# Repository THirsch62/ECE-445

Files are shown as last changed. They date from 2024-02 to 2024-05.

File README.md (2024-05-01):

# Senior Design Spring 2024 Lab Notebook
Group: Tyler Hirsch, Bryson Maedge, Nolan Opalski  
NetId: &nbsp;thirsch3, &nbsp;&nbsp;&nbsp;&nbsp;&nbsp;&nbsp;bmaedge2, &nbsp;&nbsp;&nbsp;&nbsp;&nbsp;&nbsp;&nbsp;&nbsp;nolanfo2   
TA: &nbsp;&nbsp;&nbsp;&nbsp;&nbsp;&nbsp;Angquan Yu

## May 1st, 2024
Finished our final paper today and am adding the last update to the notebook. Has been a very informative class and we all learned a lot. Thank you!

## April 30th, 2024
We each individually worked on the final paper throughout the day. Made some really solid progress only need to do the R&V Portion of the paper now.

## April 29th, 2024 (Presentation)
Today we had our presentation. We believe it went really well. It was at 8am which was a little bit of an early wakeup for us but our minds were sharp. 

## April 28th, 2024
We took the feedback from our mock presentation and edited our slides. We also ran through the presentation once and got fluid with our speaking. We are ready for this.

## April 26th, 2024 (Mock Presentation)
We met at 10AM to perform our mock presentation. We got a lot of valuable feedback that we are going to apply to our slides. Presentation went far better than the demo.

## April 25th, 2024
We met at 12:30 to review everything we compiled for our presentation. We also put together our team contract fulfillment.

## April 24th, 2024
We met briefly on discord to go over rough layout of our presentation.

## April 23rd, 2024 (Final Demo)
We demoed our project to Professor Gruev and 2 TAs. They were rather unimpressed to say the least. We didn't read the PCB requirements, so we didn't put a microcontroller on the board, so we lost points for that. We tried to explain what happened with our Raspberry Pi and the image recognition but it didn't look like they were buying it. To be fair, it does sound far-fetched. We were basically told that this stuff happens all the time and that we need to try harder.

## April 22nd, 2024
Our Raspberry Pi came in. We retested the control of all the servos to make sure that functionality worked. We started getting a lot of errors surrounding keras and tensorflow. We spent about 4 hours trying different methods to install keras and tensorflow and it wouldn't load on this Raspberry Pi.

## April 20th, 2024
At some point during the past night, 2 panels came off our project and the power port for our Raspberry Pi came off. We cut new panels and reglued them. We also ordered a new Raspberry Pi.

## April 18th, 2024 (Mock Demo)
We demoed our project to Angquan. He was very impressed with our project and to see that it was working.

## April 17th, 2024
We met at noon today to test everything folding. The board was able to fold as expected. Our image recognition was not accurate, so we painted the board black to try to achieve better results if we increased our contrast. After painting our system was correctly able to distinguish between pants and shirts.

## April 16th, 2024
Nolan glued the servos to the board at noon so they would be dry and ready for testing by tomorrow. Tyler tested all the ports on the Raspbery Pi and the PCB and made sure they were able to interact with the button, LEDs and servos.

## April 15th, 2024
Tyler and Nolan met around 3:30 to solder everything to the PCB.

## April 11th, 2024
We met at noon today. We almost finished rebuilding the project with 6 servos for control instead of 12. We also finished designing our PCB and submitted an order through JLCPCB to get our PCB in sooner.

## April 10th, 2024
We met at 2pm today. We started rebuilding our project. We had to recut panels that were suited for 1 servo.

## April 9th, 2024
We met at 2pm today. Last time we met, we were not able to emit enough voltage to power the servos. We were limited by the voltage supplied by the IC chip. After meeting today, we were still unable to resolve this issue and decided it would be easiest to switch our design to only utilize one servo.

## April 3rd, 2024
We met at 1pm today. The goal was to finalize how we could utilize transistors to control power to our servos.

## April 2nd, 2024 (Fourth Round PCB Way Deadline at 4:45pm)
We met today and finished our PCB design. We sent it over to our TA for audit and it failed. We are going to send our own order in tomorrow morning. Here is a picture of our design.

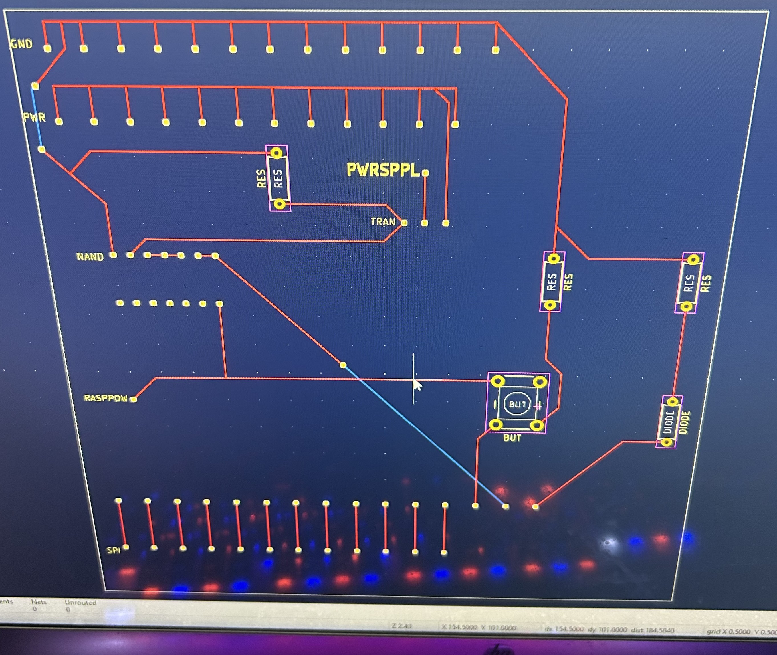
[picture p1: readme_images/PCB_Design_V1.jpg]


## April 1st, 2024
We met today at 2pm to finish glueing everything. We finished:
* Glueing servo arms to panels
* Glueing servos to risers
* Glueing camera arm mount to board
* Glueing Rasperry Pi riser to board  

Before we could attach the servos to the panels, we had to set the servos on the left of the panel to an initial position of 0 degrees, and the serovs on the right of the panel to an initial position of 180 degrees. This is because they will be turning in opposite directions. So, in the "fold-up" position, the left servo will be rotated to a 120 degree angle and the right servo will be rotated to a 60 degree angle. We ran into a problem with our Raspbeery Pi today. It kept booting on and off for about 2 hours before it stabilized. We were never able to identify the cause of the problem, but we hope it does not continue and we are forced to spend another $60 on a Raspberry Pi.

We started testing once the glue finished curing. We started by rotating the servos 18 degrees and back to the starting position and it worked great. We then tried testing it by rotating the servos 90 degrees and then back. There was a loud cracking noise and we realized we overtorqued one of the servos and it was not out of commission. One of our risers is also broken, but that's an easier fix. Now, we need to order more servos before we can continue working.

We identified the problem as the PWM signal. When our code is not running and everything is connected to power, the servos are reading a PWM duty cycle of 0%, therefore they both try to rotate to their starting position. This will cause them to break, as happened during our initial test. We decided that we could fix this problem by using a PNP transistor. If the servos have no power to them, they cannot rotate, no matter what the PWM duty cycle is. Our idea is, we will set the PWM duty cycles of all the servos and then use logic to allow power to pass through to servos. Then whenever we need to stop the program or anything, we just cut power to our servos, so they don't try to rotate to a wrong position.

The Raspberry Pi's GPIO ports has a low signal of ~1.2V and a high signal of ~4.9V. This will not work as a transistor will generally start allowing passthrough voltage at anything over ~0.7V. Therefore we will need to add an IC chip, to help control this output. The IC chip will be a NAND gate as that is the easiest to convert to an AND gate and none of the 3 of us have any AND chips. (Here is a <a href="https://www.ti.com/lit/ds/symlink/sn74ac00.pdf?ts=1711955865754&ref_url=https%253A%252F%252Feu.mouser.com%252F">link</a> to the NAND gate's data sheet) The NAND gate's output will have a high signal of ~2.1V and a low signal of ~0.1V. This will allow us to properly control a transistor. We will connect our power supply's Vin to the collector pin of the transistor and connect our servos to the emitter pin of the transistor. This will allow us to control a higher voltage circuit with a lower voltage Raspberry Pi.

We tested this today with a transistor from a previous ECE class lab kit, but the maximum throughput was 3.3V. We need 5V minimum to power our servos, so we will need to order others. We also have a fleshed out version of our PCB, but are waiting on last minute parts to test on a breadboard before we submit a PCB order.

We stopped working around 8:30PM.

We are waiting on the following parts to come in:
* Spool of 22 AWG wire
* Wire stripper
* Female to male wires
* Raspberry Pi Camera cable extension
* Replacement servos (they come in packs of 4)
* Transistors

## March 27th, 2024
We met today to get some more physical aspects of the project done. Here's what we finished today:
* Glueing dowels to panels for structural support
* Built and glued 12 risers for all servos
* Built riser for Raspberry Pi
* Built camera arm
* Built mount for camera arm

## March 25th, 2024
We met again today to start building our project. We cut out the first panels and realized we couldn't cut our dowel rods with a box cutter, so we ran back to Home Depot. We bought:
* Pruners (easy way to cut dowels)
* Another dowel (Mount camera)

On the way back, we stopped at Goodwill and bought infant clothes to demo. We finished cutting all of the dowels and started cutting the risers as well.

## March 21st, 2024
We met at noon today to revise project plans and get supplies. We decided that we would use cardboard for panels and for a base because it would be light and within our budget. We would reinforce the cardboard with dowel rods and use superglue/gorilla glue to hold everything together.

We did a Home Depot run. We bought:
* 2 Heavy duty cardboard boxes. 
    * 1 will be used as a baseplate for the entire project
    * The other will be cut up and used as panels for folding clothes and as risers for the servos
* Box cutter
    * Cut cardboard
* Dowel rod
    * Cut into pieces and used to mount servos to panels
* Gorilla glue
    * Mount risers to baseplate and servos to risers
    * Mount dowel rod to servo

## March 19th, 2024
After a series of emails were sent around, we were able to locate the rest of our Amazon order. We had a team meeting at 3pm to discuss project details and to pick up the rest of our order.<br><br>
We met with Angquan for our weekly check-in at 4pm.<br><br>
After the meeting we experimented with our Servos to make sure we could control 2 of them simultaneously.

## March 6th, 2024
We went to the ECEB to pick up our amazon order that we placed through ECE Illinois. Part of our order was missing. Started emailing around to find where the rest of the order could be.

## February 27th, 2024 (Design Review Date)
We presented our Design Document to 3 TAs and Professor Viktor Gruev. Some feedback that was provided:
* Find other voltage regulator. Linear one we are currently using allows more power dissipation.
* Use children's clothes. Will scale size of model down and can save on materials.
* Include more data about architecture and design of Image Recognition subsystem. Such as how many layers, what features we use to classify, etc., and why we chose all those.
* Add what data is being transferred in the block diagram
* Add temperature to Tolerance Analysis

## February 26th, 2024
We determined who was going to present each part of the design document tomorrow and had a few practice presentations.<br>

We found out that 3-D printing everything would be very expensive. So we decided that we'll use 2x2's or something of the like from Home Depot for the frame. A veneer or polyester sheet for the panels. And then we would 3-D print the mounting mechanisms so that we ensure a proper fit for the servos.

## Februrary 22nd, 2024 (Design Document Due Date)
We finalized our <a href="https://github.com/THirsch62/ECE-445/blob/main/Design%20Document.pdf">Design Document</a>, referencing the <a href="https://courses.engr.illinois.edu/ece445/documents/grading_rubrics/DD_evalsheet.pdf">evaluation sheet</a> to make sure that we met all the requirements.

## Februrary 21st, 2024
We met today to revise our Design Document and started CAD modeling. We determined how much 3D printing would cost us and also placed an Amazon order through ECE Illinois for all parts we need to start our initial testing.
<br><br>
Here is the start of what our panels will look like:
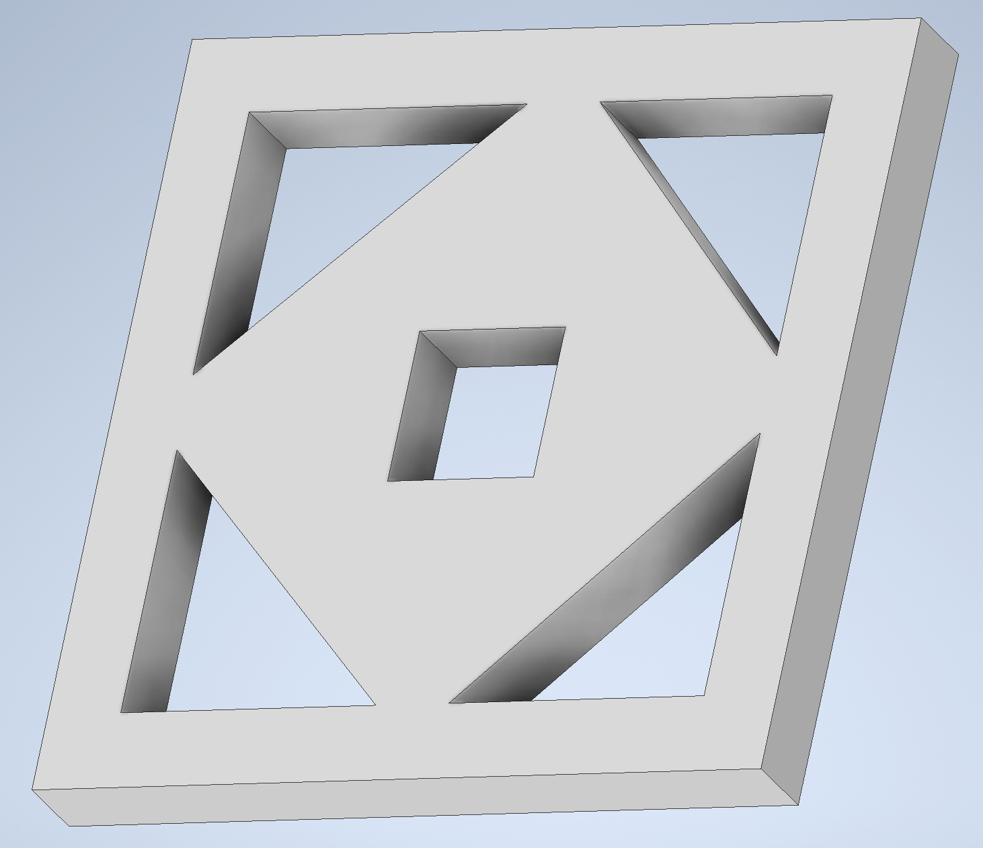
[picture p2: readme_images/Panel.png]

The dimensions are 10"x10"x1".
<br><br>
Here is our purchase order:
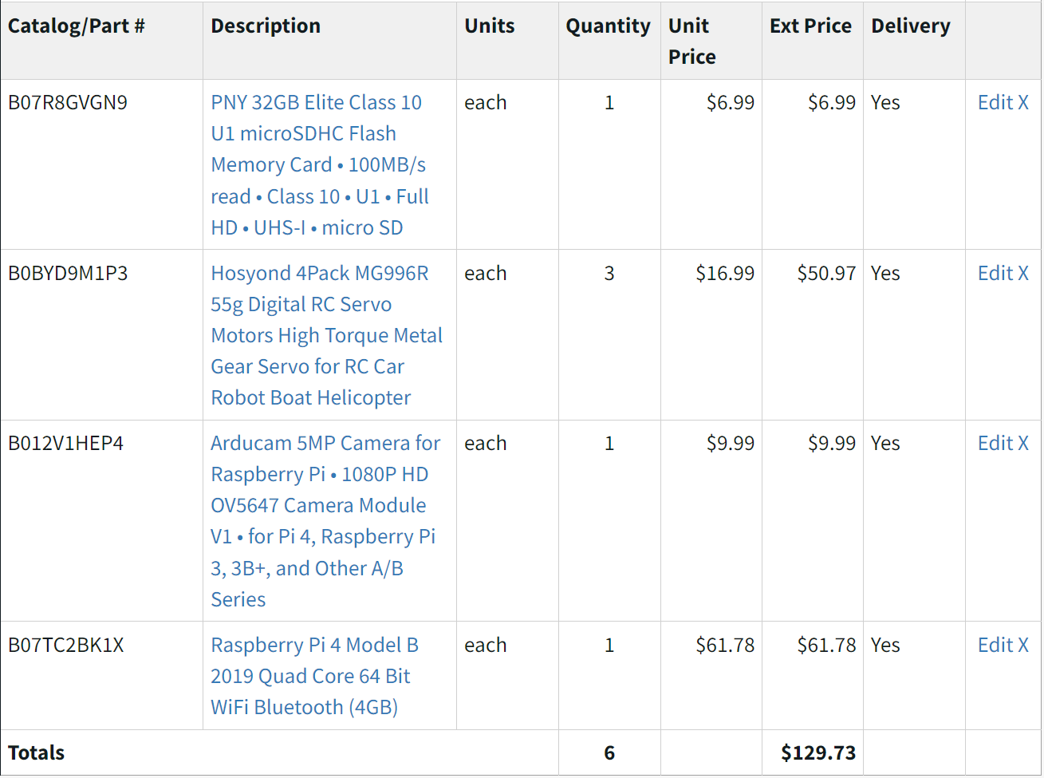
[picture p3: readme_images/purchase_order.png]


## February 20th, 2024
We finished a rough draft of our Design Document and reviewed it with our TA. We determined that our graphics should be more detailed and our verification steps should be more objective.

## February 19th 2024
We started a rough draft of our Design Document. We plan to work on it tonight and tomorrow. This way, we'll have a good outline before meeting with our TA so we can get any help if needed.

## February 18th 2024
Sent emails asking for discounts/sponsored free parts to:
- DFRobots (Servos)
- RaspberryPi (RaspberryPi4 and camera module)
- Siebel Center for Design (3-D printing)

## February 12th 2024
We discussed parts required for initial testing:
* Servos
* RaspberryPi 4
* Camera
* Frame to mount servos to
* Panel to attach to servos and test folding mechanism

We put together a shopping list with amazon links to stuff we need to purchase for testing so we can discuss purchasing procedure with our TA tomorrow. We also need to discuss the procedure for getting CAD models 3-D printed as our frame and panels will most likely be 3-D printed.

## February 9th 2024 (Team Contract Due Date)
We discussed guidelines, goals and expectations today. Following that discussion, we put together our <a href="https://github.com/THirsch62/ECE-445/blob/main/ECE445_Team_48_Contract.pdf">Team Contract</a> and submitted on Canvas.

## February 8th 2024 (Project Proposal Due Date)
We collaborated over discord to make revisions in accordance to feedback provided by our Ta.  
<a href="https://github.com/THirsch62/ECE-445/blob/main/Project%20Proposal.pdf">Project Proposal</a> was submitted by Nolan on Canvas.
<br><br>
Started <a href="https://github.com/THirsch62/ECE-445/tree/main/python_code">python code</a> for image recognition:
* Import dataset from MNIST
* Isolate and extract part of data we need (training images and labels for: tshirts, pullovers, trousers)
* Train CNN on extracted data (model predicts with 97.7% accuracy on test dataset)
* Save trained model to sdcard
* Load trained model into memory
* Function to accept image and output predicted classification

Miscellaneous code:
* Created general layout for future functions
* TODO: Function to normalize image from camera. Will consist of cropping image to just clothing item and resizing image to 28x28 pixels
* TODO: Set up basic servo control function. Input parameter will be int corresponding to panel to fold. Function will execute folding for that panel
* TODO: Figure out folding pattern/series of ints to pass to servo control function. Need 3 foloding patterns for all clothing types

## February 7th 2024 (First TA meeting)
We met with our TA (Angquan Yu) at 4pm. Recieved feedback on current status of our project Proposal.  
Feedback summary:  
* Needs to be more detailed
* Clarified that PCB will be part of servo subsystem in our physical system  

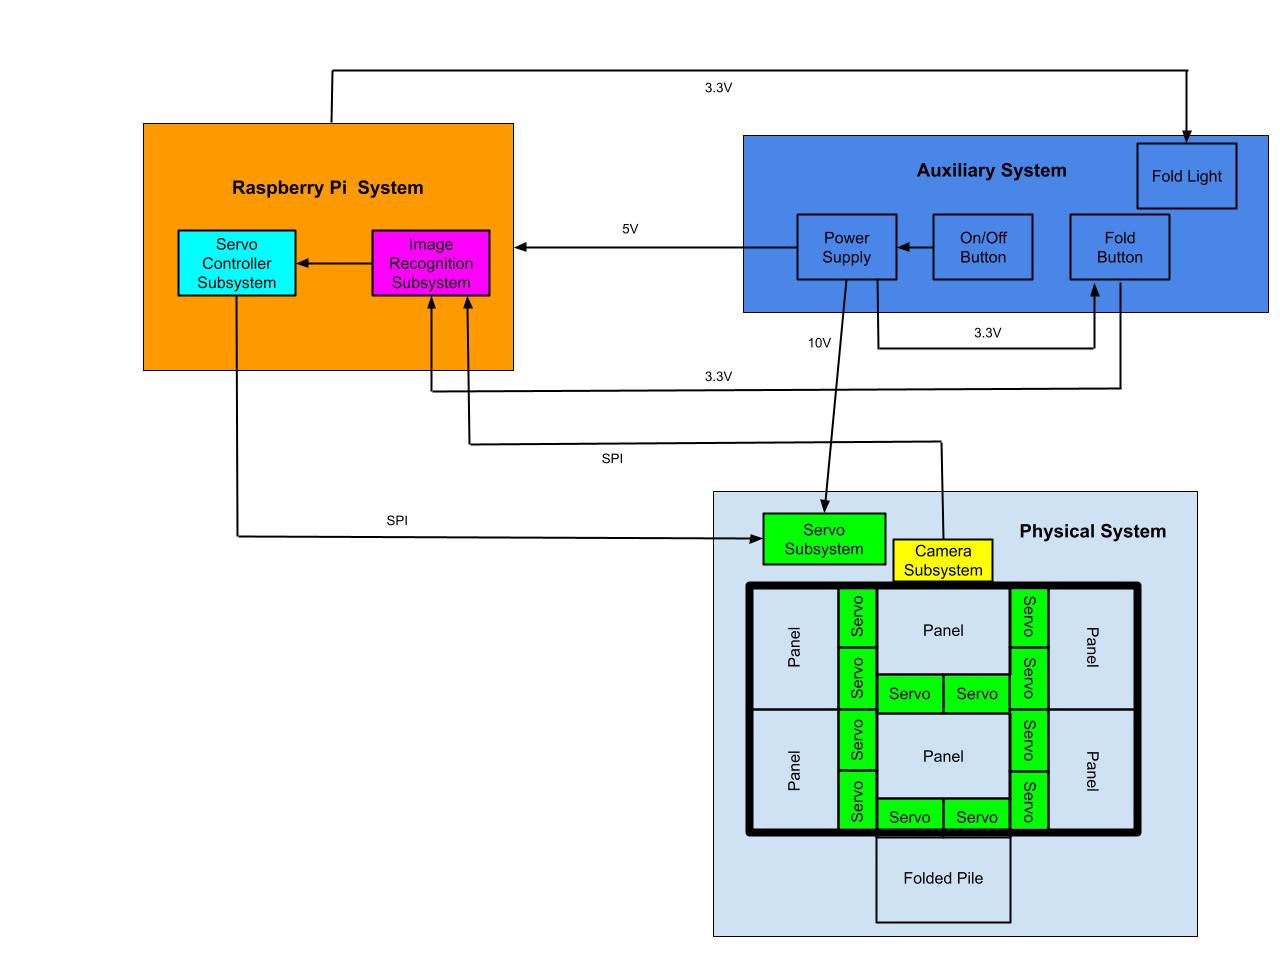
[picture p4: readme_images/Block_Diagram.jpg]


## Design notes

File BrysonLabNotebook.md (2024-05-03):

# Senior Design Spring 2024 Lab Notebook Bryson
Group: Tyler Hirsch, Bryson Maedge, Nolan Opalski  
NetId: &nbsp;thirsch3, &nbsp;&nbsp;&nbsp;&nbsp;&nbsp;&nbsp;bmaedge2, &nbsp;&nbsp;&nbsp;&nbsp;&nbsp;&nbsp;&nbsp;&nbsp;nolanfo2   
TA: &nbsp;&nbsp;&nbsp;&nbsp;&nbsp;&nbsp;Angquan Yu

## May 2nd, 2024
Added some personal thoughts to each entry of the lab notebook to make it pertain more specifically to me. Had a lot of the same information as this project was truly collaborative. Each time we met we usually met as a group and worked on it. Also turned in lab materials on time.

## May 1st, 2024
Finished our final paper today and am adding the last update to the notebook. Has been a very informative class and we all learned a lot. Thank you!

## April 30th, 2024
We each individually worked on the final paper throughout the day. Made some really solid progress only need to do the R&V Portion of the paper now. Feels very high quality. Need to add some details throughout.

## April 29th, 2024 (Presentation)
Today we had our presentation. We believe it went really well. It was at 8am which was a little bit of an early wakeup for us but our minds were sharp. I believe the professor enjoyed it and liked how we took his feedback and advocated for ourself.

## April 28th, 2024
We took the feedback from our mock presentation and edited our slides. We also ran through the presentation once and got fluid with our speaking. We are ready for this. Feeling wayyyy better than I did for the demo. 

## April 26th, 2024 (Mock Presentation)
We met at 10AM to perform our mock presentation. We got a lot of valuable feedback that we are going to apply to our slides. Presentation went far better than the demo. The communication related TA helped a lot with our actual presentation skills and the course TA helped us refine some technical displays of our project. Feeling confident going into the presentation.

## April 25th, 2024
We met at 12:30 to review everything we compiled for our presentation. We also put together our team contract fulfillment.

## April 24th, 2024
We met briefly on discord to go over rough layout of our presentation. Worked on some seperation of parts and who is going to say what. We are all good presenters so I am not worried,

## April 23rd, 2024 (Final Demo)
We demoed our project to Professor Gruev and 2 TAs. They were rather unimpressed to say the least. We didn't read the PCB requirements, so we didn't put a microcontroller on the board, so we lost points for that. We tried to explain what happened with our Raspberry Pi and the image recognition but it didn't look like they were buying it. To be fair, it does sound far-fetched. We were basically told that this stuff happens all the time and that we need to try harder. We got some really good feedback that I am glad to have heard. In the future, when I encounter problems I am going to make sure to better advocate what we did to solve them. I am kind of upset at how little we tried to explain our solution attempts because it would have made a much bigger difference. But now it is presentation time.

## April 22nd, 2024
Our Raspberry Pi came in. We retested the control of all the servos to make sure that functionality worked. We started getting a lot of errors surrounding keras and tensorflow. We spent about 4 hours trying different methods to install keras and tensorflow and it wouldn't load on this Raspberry Pi. I dont fully understand the problem since Tyler is the code wiz but things are starting to look bleak. Our image recognition just took a major step back and now it is time to demo.

## April 20th, 2024
2 panels fell off the project I noticed as I walked downstairs. We had to reglue them and do other little maintenance things like replace a servo that was not angling correctly. All went without a hitch.

## April 18th, 2024 (Mock Demo)
Tyler and Nolan demoed the project to Angquan. I was still studying for test but it worked. Was concerned about the paint, but our wires seem fine.

## April 17th, 2024
We met at noon today to test everything folding. The board was able to fold as expected. Our image recognition was not accurate, so me and Nolan painted the board black to try to achieve better results if we increased our contrast. After painting our system was correctly able to distinguish between pants and shirts. The paint hopefully did not get in any of the wiring which is a concern. We protected our servos so we will test once it dries.

## April 15-16th, 2024
Nolan and tyler did some soldering and some glueing. I had a test that I was studying for so was unable to be there.

## April 11th, 2024
We met at noon today. We almost finished rebuilding the project with 6 servos for control instead of 12. We then designed our PCB with me editing some footprints to fit our datasheet specific designs. We are going to submit an order on our own and fast track it so that we have time to mess around with it.

## April 10th, 2024
We met at 2pm today. We started rebuilding our project. I recut each panel and new risers for the servos in the morning. This allowed us to start working and thinking of new solutions right away.

## April 9th, 2024
We met at 2pm today. Last time we met, we were not able to emit enough voltage to power the servos. We were limited by the voltage supplied by the IC chip. After meeting today, we were still unable to resolve this issue and decided it would be easiest to switch our design to only utilize one servo.

## April 3rd, 2024
We met at 1pm today. The goal was to finalize how we could utilize transistors to control power to our servos. Nothing worked we need to rethink.

## April 2nd, 2024 (Fourth Round PCB Way Deadline at 4:45pm)
We met today and finished our PCB design. We sent it over to our TA for audit and it failed. We are going to send our own order in tomorrow morning. Here is a picture of our design. I am going to use my Kicad experience to make new PCB design hopefully we only need to order once.



## April 1st, 2024
We met today at 2pm to finish glueing everything. We finished:
* Glueing servo arms to panels
* Glueing servos to risers
* Glueing camera arm mount to board
* Glueing Rasperry Pi riser to board  

Before we could attach the servos to the panels, we had to set the servos on the left of the panel to an initial position of 0 degrees, and the serovs on the right of the panel to an initial position of 180 degrees. This is because they will be turning in opposite directions. So, in the "fold-up" position, the left servo will be rotated to a 120 degree angle and the right servo will be rotated to a 60 degree angle. We ran into a problem with our Raspbeery Pi today. It kept booting on and off for about 2 hours before it stabilized. We were never able to identify the cause of the problem, but we hope it does not continue and we are forced to spend another $60 on a Raspberry Pi.

We started testing once the glue finished curing. We started by rotating the servos 18 degrees and back to the starting position and it worked great. We then tried testing it by rotating the servos 90 degrees and then back. There was a loud cracking noise and we realized we overtorqued one of the servos and it was not out of commission. One of our risers is also broken, but that's an easier fix. Now, we need to order more servos before we can continue working.

We identified the problem as the PWM signal. When our code is not running and everything is connected to power, the servos are reading a PWM duty cycle of 0%, therefore they both try to rotate to their starting position. This will cause them to break, as happened during our initial test. We decided that we could fix this problem by using a PNP transistor. If the servos have no power to them, they cannot rotate, no matter what the PWM duty cycle is. Our idea is, we will set the PWM duty cycles of all the servos and then use logic to allow power to pass through to servos. Then whenever we need to stop the program or anything, we just cut power to our servos, so they don't try to rotate to a wrong position.

The Raspberry Pi's GPIO ports has a low signal of ~1.2V and a high signal of ~4.9V. This will not work as a transistor will generally start allowing passthrough voltage at anything over ~0.7V. Therefore we will need to add an IC chip, to help control this output. The IC chip will be a NAND gate as that is the easiest to convert to an AND gate and none of the 3 of us have any AND chips. (Here is a <a href="https://www.ti.com/lit/ds/symlink/sn74ac00.pdf?ts=1711955865754&ref_url=https%253A%252F%252Feu.mouser.com%252F">link</a> to the NAND gate's data sheet) The NAND gate's output will have a high signal of ~2.1V and a low signal of ~0.1V. This will allow us to properly control a transistor. We will connect our power supply's Vin to the collector pin of the transistor and connect our servos to the emitter pin of the transistor. This will allow us to control a higher voltage circuit with a lower voltage Raspberry Pi.

We tested this today with a transistor from a previous ECE class lab kit, but the maximum throughput was 3.3V. We need 5V minimum to power our servos, so we will need to order others. We also have a fleshed out version of our PCB, but are waiting on last minute parts to test on a breadboard before we submit a PCB order.

We stopped working around 8:30PM.

We are waiting on the following parts to come in:
* Spool of 22 AWG wire
* Wire stripper
* Female to male wires
* Raspberry Pi Camera cable extension
* Replacement servos (they come in packs of 4)
* Transistors

## March 27th, 2024
We met today to get some more physical aspects of the project done. Here's what we finished today:
* Glueing dowels to panels for structural support
* Built and glued 12 risers for all servos
* Built riser for Raspberry Pi
* Built camera arm
* Built mount for camera arm
Got a lot done. I am going to reglue and reinforce some of the dowels tonight since the project is at my house.

## March 25th, 2024
We met again today to start building our project. We cut out the first panels and realized we couldn't cut our dowel rods with a box cutter, so we ran back to Home Depot. We debated pruners or a saw but the pruners won for simplicity.
We bought:
* Pruners (easy way to cut dowels)
* Another dowel (Mount camera)

On the way back, we stopped at Goodwill and bought infant clothes to demo. It was awkward to have three college guys buying infant clothes haha. We finished cutting all of the dowels and started cutting the risers as well. Dowels did not cut as clean as we hoped but overall it worked well.

## March 21st, 2024
Met at noon today. Despite the ugly look we are going to use cardboard because its cheap and easy to manipulate. We would reinforce the cardboard with dowel rods and use superglue/gorilla glue to hold everything together. Hopefully this allows our servos to connect flawlessly.

We did a Home Depot run. We bought:
* 2 Heavy duty cardboard boxes. 
    * 1 will be used as a baseplate for the entire project
    * The other will be cut up and used as panels for folding clothes and as risers for the servos
* Box cutter
    * Cut cardboard
* Dowel rod
    * Cut into pieces and used to mount servos to panels
* Gorilla glue
    * Mount risers to baseplate and servos to risers
    * Mount dowel rod to servo

## March 19th, 2024
After a series of emails were sent around, we were able to locate the rest of our Amazon order. We had a team meeting at 3pm to discuss project details and to pick up the rest of our order.<br><br>
We met with Angquan for our weekly check-in at 4pm.<br><br>
After the meeting we experimented with our Servos to make sure we could control 2 of them simultaneously. We had some issues regarding this need to reconsider design or amplify voltage using transistors.

## March 6th, 2024
We went to the ECEB to pick up our amazon order that we placed through ECE Illinois. Part of our order was missing. Started emailing around to find where the rest of the order could be. Worried it was lost in the mail.

## February 27th, 2024 (Design Review Date)
We presented our Design Document to 3 TAs and Professor Viktor Gruev. Some feedback that was provided:
* Find other voltage regulator. Linear one we are currently using allows more power dissipation.
* Use children's clothes. Will scale size of model down and can save on materials. This ended up saving us a lot of headache.
* Include more data about architecture and design of Image Recognition subsystem. Such as how many layers, what features we use to classify, etc., and why we chose all those.
* Add what data is being transferred in the block diagram
* Add temperature to Tolerance Analysis using the equation we already had on our design doc. 

Great feedback feel like we are in a better position now.

## February 26th, 2024
We determined who was going to present each part of the design document tomorrow and had a few practice presentations.<br>

We found out that 3-D printing everything would be very expensive. We are looking at different materials to make the panels. Planning a trip to home depot to check out some possible options.

## Februrary 22nd, 2024 (Design Document Due Date)
We finalized our <a href="https://github.com/THirsch62/ECE-445/blob/main/Design%20Document.pdf">Design Document</a>, referencing the <a href="https://courses.engr.illinois.edu/ece445/documents/grading_rubrics/DD_evalsheet.pdf">evaluation sheet</a> to make sure that we met all the requirements.

## Februrary 21st, 2024
We met today to revise our Design Document and started CAD modeling. We determined how much 3D printing would cost us and also placed an Amazon order through ECE Illinois for all parts we need to start our initial testing. 3D printing was too pricy we are going to have to reconsider.

## February 20th, 2024
We finished a rough draft of our Design Document and reviewed it with our TA. We determined that our graphics should be more detailed and our verification steps should be more objective. Making the graphics proved to be challenging software wise.

## February 19th 2024
We started a rough draft of our Design Document. We plan to work on it tonight and tomorrow. This way, we'll have a good outline before meeting with our TA so we can get any help if needed. Went well still on good progress.

## February 18th 2024
Called and requested 3D printing pricing. Sent some emails regarding 3D printing as well.

## February 12th 2024
We discussed parts required for initial testing:
* Servos
* RaspberryPi 4
* Camera
* Frame to mount servos to
* Panel to attach to servos and test folding mechanism

We put together a shopping list with amazon links to stuff we need to purchase over discord for testing so we can discuss purchasing procedure with our TA tomorrow. We are going to work on CAD next for the camera mount and paneling. We need to check pricing for that.

## February 9th 2024 (Team Contract Due Date)
We discussed guidelines, goals and expectations today. Following that discussion, we put together our <a href="https://github.com/THirsch62/ECE-445/blob/main/ECE445_Team_48_Contract.pdf">Team Contract</a> and submitted on Canvas. Overall, we are on good track.

## February 8th 2024 (Project Proposal Due Date)
We collaborated over discord to make revisions in accordance to feedback provided by our Ta.  
<a href="https://github.com/THirsch62/ECE-445/blob/main/Project%20Proposal.pdf">Project Proposal</a> was submitted by Nolan on Canvas.
Tyler started to work on the code.

## February 7th 2024 (First TA meeting)
We met with our TA (Angquan Yu) at 4pm. Recieved feedback on current status of our project Proposal. This information is listed below and will be used in our project report.
Feedback summary:  
* Needs to be more detailed
* Clarified that PCB will be part of servo subsystem in our physical system  



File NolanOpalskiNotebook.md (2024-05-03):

# Senior Design Spring 2024 Lab Notebook
Group: Team 48
Name: Nolan Opalski  
NetId: nolanfo2   
TA: Angquan Yu
The group was extremely colaborative, everything was done with each other so notebook entries will bascially be the same

## May 1st, 2024
Objective: Finish Our Paper and Update Lab Notebook

Finished our final paper today and am adding the last update to the notebook. Has been a very informative class and we all learned a lot. Thank you!

## April 30th, 2024
Objective: Work on Final Paper

We each individually worked on the final paper throughout the day. Made some really solid progress only need to do the R&V Portion of the paper now.
I wrote sections of design procedure (power) and design detail (panels, servos, auxillary systems)
Attended peer final presentation for group 75 at 8:30am

## April 29th, 2024 (Presentation)
Objective: Complete Final Presentation

Today we had our presentation. We believe it went really well. It was at 8am, very early for me.
## April 28th, 2024
Objective: Improve Presentation

We took the feedback from our mock presentation and edited our slides. We also ran through the presentation once and got fluid with our speaking.

## April 26th, 2024 (Mock Presentation)
Objective: Present Mock Presentation

We met at 10AM to perform our mock presentation. We got a lot of valuable feedback that we are going to apply to our slides. Presentation went far better than the demo.

## April 25th, 2024
Objective: Contract Fulfillment and Review for Presentation

We met at 12:30 to review our presentation and work on finish team contract fulfillment.

## April 24th, 2024
Objective: Work on Presentation

Met briefly on discord to go over rough layout of our presentation.

## April 23rd, 2024 (Final Demo)
Objective: Complete Final Demo

We demoed our project to Professor Gruev and 2 TAs. Demo did not go well. We didn't read the PCB requirements, so we didn't put a microcontroller on the board, so we lost points for that. We tried to explain what happened with our Raspberry Pi and the image recognition but it didn't look like they were buying it. We were basically told that this stuff happens all the time and that we need to try harder.

## April 22nd, 2024
Objective: Connect new RaspberryPi and test functionality

Our Raspberry Pi came in. We retested the control of all the servos to make sure that functionality worked. We started getting a lot of errors surrounding keras and tensorflow. We spent about 4 hours trying different methods to install keras and tensorflow and it wouldn't load on this Raspberry Pi.

## April 20th, 2024
Objective: Reconstruct Project

At some point during the past night, 2 panels came off our project and the power port for our Raspberry Pi came off. We cut new panels and reglued them. We also ordered a new Raspberry Pi.

## April 18th, 2024 (Mock Demo)
Objective: Complete Mock Demo

We demoed our project to Angquan. He was very impressed with our project and to see that it was working.

## April 17th, 2024
Objective: Prepare for Mock Demo

We met at noon today to test everything folding. The board was able to fold as expected. Our image recognition was not accurate, so we painted the board black to try to achieve better results if we increased our contrast. After painting our system was correctly able to distinguish between pants and shirts.

## April 16th, 2024
Objective: Prepare for Mock Demo

I glued the servos to the board at noon so they would be dry and ready for testing by tomorrow. Tyler tested all the ports on the Raspbery Pi and the PCB and made sure they were able to interact with the button, LEDs and servos.

## April 15th, 2024
Objective: Solder PCB

Tyler and I met around 3:30 to solder everything to the PCB.

## April 11th, 2024
Objective: Rebuild Project and Complete PCB Design and Order PCB

We met at noon today. We almost finished rebuilding the project with 6 servos for control instead of 12. 
We also finished designing our PCB and submitted an order through JLCPCB to get our PCB in sooner.

## April 10th, 2024
Objective: Rebuild Project

We met at 2pm today. We started rebuilding our project. We had to recut panels that were suited for 1 servo.

## April 9th, 2024
Objective: Figure out how to Power Servos

We met at 2pm today. Last time we met, we were not able to emit enough voltage to power the servos. We were limited by the voltage supplied by the IC chip. After meeting today, we were still unable to resolve this issue and decided it would be easiest to switch our design to only utilize one servo.

## April 3rd, 2024
Objective: Figure out how to Power Servos

We met at 1pm today. Did not find any effective method of finding out how to power servos. Need to redesign PCB.

## April 2nd, 2024 (Fourth Round PCB Way Deadline at 4:45pm)
Objective: Finish PCB Design

We met today and finished our PCB design. We sent it over to our TA for audit and it failed. We are going to send our own order in tomorrow morning. Here is a picture of our design.


## April 1st, 2024
Objective: Finish Glueing

We met today at 2pm to finish glueing everything. We finished:
* Glueing servo arms to panels
* Glueing servos to risers
* Glueing camera arm mount to board
* Glueing Rasperry Pi riser to board  

Before we could attach the servos to the panels, we had to set the servos on the left of the panel to an initial position of 0 degrees, and the serovs on the right of the panel to an initial position of 180 degrees. This is because they will be turning in opposite directions. So, in the "fold-up" position, the left servo will be rotated to a 120 degree angle and the right servo will be rotated to a 60 degree angle. We ran into a problem with our Raspbeery Pi today. It kept booting on and off for about 2 hours before it stabilized. We were never able to identify the cause of the problem, but we hope it does not continue and we are forced to spend another $60 on a Raspberry Pi.

We started testing once the glue finished curing. We started by rotating the servos 18 degrees and back to the starting position and it worked great. We then tried testing it by rotating the servos 90 degrees and then back. There was a loud cracking noise and we realized we overtorqued one of the servos and it was not out of commission. One of our risers is also broken, but that's an easier fix. Now, we need to order more servos before we can continue working.

We identified the problem as the PWM signal. When our code is not running and everything is connected to power, the servos are reading a PWM duty cycle of 0%, therefore they both try to rotate to their starting position. This will cause them to break, as happened during our initial test. We decided that we could fix this problem by using a PNP transistor. If the servos have no power to them, they cannot rotate, no matter what the PWM duty cycle is. Our idea is, we will set the PWM duty cycles of all the servos and then use logic to allow power to pass through to servos. Then whenever we need to stop the program or anything, we just cut power to our servos, so they don't try to rotate to a wrong position.

The Raspberry Pi's GPIO ports has a low signal of ~1.2V and a high signal of ~4.9V. This will not work as a transistor will generally start allowing passthrough voltage at anything over ~0.7V. Therefore we will need to add an IC chip, to help control this output. The IC chip will be a NAND gate as that is the easiest to convert to an AND gate and none of the 3 of us have any AND chips. (Here is a <a href="https://www.ti.com/lit/ds/symlink/sn74ac00.pdf?ts=1711955865754&ref_url=https%253A%252F%252Feu.mouser.com%252F">link</a> to the NAND gate's data sheet) The NAND gate's output will have a high signal of ~2.1V and a low signal of ~0.1V. This will allow us to properly control a transistor. We will connect our power supply's Vin to the collector pin of the transistor and connect our servos to the emitter pin of the transistor. This will allow us to control a higher voltage circuit with a lower voltage Raspberry Pi.

We tested this today with a transistor from a previous ECE class lab kit, but the maximum throughput was 3.3V. We need 5V minimum to power our servos, so we will need to order others. We also have a fleshed out version of our PCB, but are waiting on last minute parts to test on a breadboard before we submit a PCB order.

We stopped working around 8:30PM.

We are waiting on the following parts to come in:
* Spool of 22 AWG wire
* Wire stripper
* Female to male wires
* Raspberry Pi Camera cable extension
* Replacement servos (they come in packs of 4)
* Transistors

## March 27th, 2024
Objective: Build Physical Machine

We met today to get some more physical aspects of the project done. Here's what we finished today:
* Glueing dowels to panels for structural support
* Built and glued 12 risers for all servos
* Built riser for Raspberry Pi
* Built camera arm
* Built mount for camera arm

## March 25th, 2024
Objective: Begin Building Physical Machine

We met again today to start building our project. We cut out the first panels and realized we couldn't cut our dowel rods with a box cutter, so we ran back to Home Depot. We bought:
* Pruners (easy way to cut dowels)
* Another dowel (Mount camera)

On the way back, we stopped at Goodwill and bought infant clothes to demo. We finished cutting all of the dowels and started cutting the risers as well.

## March 21st, 2024
Objective: Buy Supplies

We met at noon today to revise project plans and get supplies. We decided that we would use cardboard for panels and for a base because it would be light and within our budget. We would reinforce the cardboard with dowel rods and use superglue/gorilla glue to hold everything together.

We did a Home Depot run. We bought:
* 2 Heavy duty cardboard boxes. 
    * 1 will be used as a baseplate for the entire project
    * The other will be cut up and used as panels for folding clothes and as risers for the servos
* Box cutter
    * Cut cardboard
* Dowel rod
    * Cut into pieces and used to mount servos to panels
* Gorilla glue
    * Mount risers to baseplate and servos to risers
    * Mount dowel rod to servo

## March 19th, 2024
Objective: Find Amazon Order

After a series of emails were sent around, we were able to locate the rest of our Amazon order. We had a team meeting at 3pm to discuss project details and to pick up the rest of our order.<br><br>
We met with Angquan for our weekly check-in at 4pm.<br><br>
After the meeting we experimented with our Servos to make sure we could control 2 of them simultaneously.

## March 6th, 2024
Objective: Pick Up Amazon Order

We went to the ECEB to pick up our amazon order that we placed through ECE Illinois. Part of our order was missing. Started emailing around to find where the rest of the order could be.

## February 27th, 2024 (Design Review Date)
Objective: Complete Design Review

We presented our Design Document to 3 TAs and Professor Viktor Gruev. Some feedback that was provided:
* Find other voltage regulator. Linear one we are currently using allows more power dissipation.
* Use children's clothes. Will scale size of model down and can save on materials.
* Include more data about architecture and design of Image Recognition subsystem. Such as how many layers, what features we use to classify, etc., and why we chose all those.
* Add what data is being transferred in the block diagram
* Add temperature to Tolerance Analysis

## February 26th, 2024
Objective: Prepare for Design Review

We determined who was going to present each part of the design document tomorrow and had a few practice presentations.<br>

We found out that 3-D printing everything would be very expensive. So we decided that we'll use 2x2's or something of the like from Home Depot for the frame. A veneer or polyester sheet for the panels. And then we would 3-D print the mounting mechanisms so that we ensure a proper fit for the servos.

## Februrary 22nd, 2024 (Design Document Due Date)
Objective: Finalize Design Document

We finalized our <a href="https://github.com/THirsch62/ECE-445/blob/main/Design%20Document.pdf">Design Document</a>, referencing the <a href="https://courses.engr.illinois.edu/ece445/documents/grading_rubrics/DD_evalsheet.pdf">evaluation sheet</a> to make sure that we met all the requirements.

## Februrary 21st, 2024
Objective: Revise Design Document and CAD model Panels

We met today to revise our Design Document and started CAD modeling. We determined how much 3D printing would cost us and also placed an Amazon order through ECE Illinois for all parts we need to start our initial testing.
<br><br>
Here is the start of what our panels will look like:

The dimensions are 10"x10"x1".
<br><br>
Here is our purchase order:


## February 20th, 2024
Objective: Complete Rough Draft of Design Document

We finished a rough draft of our Design Document and reviewed it with our TA. We determined that our graphics should be more detailed and our verification steps should be more objective.

## February 19th 2024
Objective: Work on Design Document

We started a rough draft of our Design Document. We plan to work on it tonight and tomorrow. This way, we'll have a good outline before meeting with our TA so we can get any help if needed.

## February 18th 2024
Objective: Find Funding

Sent emails asking for discounts/sponsored free parts to:
- DFRobots (Servos)
- RaspberryPi (RaspberryPi4 and camera module)
- Siebel Center for Design (3-D printing)

## February 12th 2024
Objective: Brainstorm Design

We discussed parts required for initial testing:
* Servos
* RaspberryPi 4
* Camera
* Frame to mount servos to
* Panel to attach to servos and test folding mechanism

We put together a shopping list with amazon links to stuff we need to purchase for testing so we can discuss purchasing procedure with our TA tomorrow. We also need to discuss the procedure for getting CAD models 3-D printed as our frame and panels will most likely be 3-D printed.

## February 9th 2024 (Team Contract Due Date)
Objective: Brainstorm Design and Team Contract

We discussed guidelines, goals and expectations today. Following that discussion, we put together our <a href="https://github.com/THirsch62/ECE-445/blob/main/ECE445_Team_48_Contract.pdf">Team Contract</a> and submitted on Canvas.

## February 8th 2024 (Project Proposal Due Date)
Objective: Finish Project Proposal and work on image training code

We collaborated over discord to make revisions in accordance to feedback provided by our Ta.  
<a href="https://github.com/THirsch62/ECE-445/blob/main/Project%20Proposal.pdf">Project Proposal</a> was submitted by Nolan on Canvas.
<br><br>
Started <a href="https://github.com/THirsch62/ECE-445/tree/main/python_code">python code</a> for image recognition:
* Import dataset from MNIST
* Isolate and extract part of data we need (training images and labels for: tshirts, pullovers, trousers)
* Train CNN on extracted data (model predicts with 97.7% accuracy on test dataset)
* Save trained model to sdcard
* Load trained model into memory
* Function to accept image and output predicted classification

Miscellaneous code:
* Created general layout for future functions
* TODO: Function to normalize image from camera. Will consist of cropping image to just clothing item and resizing image to 28x28 pixels
* TODO: Set up basic servo control function. Input parameter will be int corresponding to panel to fold. Function will execute folding for that panel
* TODO: Figure out folding pattern/series of ints to pass to servo control function. Need 3 foloding patterns for all clothing types

## February 7th 2024 (First TA meeting)
Objective: Meet with TA

We met with our TA (Angquan Yu) at 4pm. Recieved feedback on current status of our project Proposal.  
Feedback summary:  
* Needs to be more detailed
* Clarified that PCB will be part of servo subsystem in our physical system  



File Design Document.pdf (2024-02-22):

# ECE 445

## Spring 2024

## Senior Design Design Document

# Automated Multi-Mode Garment Folding System with Arduino Control

Team 48
Tyler Hirsch
Bryson Maedge
Nolan Opalski
February 22nd 2023
TA: Angquan Yu

# Table Of Contents

Link to Github Notebook: Github Notebook (https://github.com/THirsch62/ECE-445)

# 1. Introduction

## 1.1 Problem

No one likes to fold laundry. It's dull, boring, and tedious. The only positive is that it gives you an excuse to listen to your favorite podcast that you may have had a backlog on. On top of that, folding laundry can prove to be a difficult task for the elderly and disabled. In commercial settings, employees of large retail clothing stores have reported getting carpal tunnel syndrome from the repetitive and manual task of folding clothes. Referencing the ADA, there are a long list of reasons that folding laundry can be difficult for people with physical disabilities. Our project would help mitigate these issues for people with physical disabilities. Our solution expands upon previous designs by offering multiple modes, a more compact size, and a cheaper alternative.

## 1.2 Solution

To solve this crisis, we want to create an automated multi-mode clothes folding system. This will allow the user to decrease the time and effort involved in folding laundry. The whole process takes place in three steps. A user will place one of three preset clothing items on the machine. An overhead camera is used to image the clothing item and send the data to a Raspberry Pi controller. The controller will run the image through a python program that will identify the item of clothing then send a series of instructions out to servos. The servos will operate mechanical folding panels that will properly fold the clothing item. A final panel will place the folded item into a pile.

## 1.3 Visual Aid

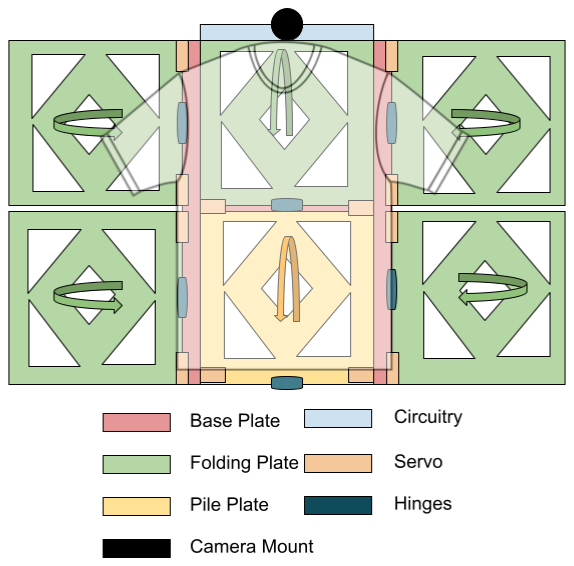
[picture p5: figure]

## 1.4 High-Level Requirements

- Image Recognition
- The machine must be able to identify three different clothing items: t-shirt, pullover, trousers. To implement this, we will store a pre-trained ML algorithm that will accept an image and output the predicted clothing type. In order to consider this achieved, we will be requiring a correct clothing identification rate of 90%.
- Correct Folding Instructions
- Raspberry Pi code must be able to correctly know what is on the folding machine using image analysis software described above. Once the correct item is determined, one of the three folding processes is selected and carried out. These folding instructions will be determined beforehand following conventional folding techniques. In order to consider this achieved, the machine must output the same exact instructions for the clothing type it identifies. This goal is independent of the image recognition goal. That means that if the machine incorrectly identifies a pullover as a pair of pants, we still expect the machine to carry out the folding algorithm for pants to be considered a success.
- Correct Folding Mechanic
- Servos and Panels must be able to properly fold and pile the clothes neatly and in good time. The folding mechanics will be predetermined and follow conventional folding techniques as described above. This will be considered complete when the clothes folded are in a neat condition with little to no incorrect overlap. The servos must also fold the clothes in a time less than 5 seconds.

# 2. Design

## 2.1 Block Diagram

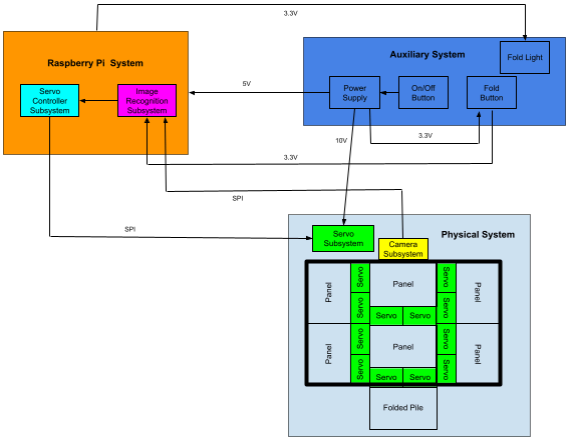
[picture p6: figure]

## 2.2 System Overview and Requirements

- RaspberryPi System
- Servo-Controller Subsystem
■ The servo controller will contain three different programs, one for each type of clothing. Depending on the type of clothing identified by the image recognition subsystem, the servo controller will pick the corresponding program.
■ Each program will control sets of servos in a sequential manner, allowing the previous set of servos to return to their original position before activating the next set.
■ The Raspberry Pi system will be connected to the servo motors through a PCB chip.
Requirement | Verification
The servo controller will contain three different programs, one for each type of clothing | - The servos are able to move in a way indicative of the three programs that are programmed
- Image Recognition Subsystem
■ The image recognition system will be written in python and called on system boot. We will train a Convolutional Neural Network (https://www.tensorflow.org/tutorials/images/cnn) model provided by Tensorflow on a Fashion MNIST dataset (https://keras.io/api/datasets/fashion_mnist/) provided by TensorFlow’s Keras.
■ The fashion dataset contains about 18,000 images for the 3 labels (t-shirts, pullovers, trousers) that we will be using. We should be able to achieve at least a 90% correct classification rate.
■ We will use Keras’s save feature to save and store the model to our micro-sd card. This will save significant time and memory during the boot phase of our automatic-folder. The model will be loaded into memory on system boot and the prediction function will take an image as a parameter. The model should be able to output a correct classification within 1 second of getting called.
■ Upon receiving a high signal from the fold button, the RaspberryPi will save a frame of the streamed video. It will pass this frame to the prediction method of the CNN model. It will then pass the output of the prediction method to the servo controller subsystem.

Requirement | Verification
Image Recognition subsystem will identify three different articles of clothing | - System can properly crop picture so that only clothing item is in view - System can resize cropped picture to 28x28 pixels - System can predict clothing type from resized, cropped images with at least 90% accuracy.
- Auxiliary System
- Power Supply
■ Must be able to supply stable voltage for multiple subsystems that will each require different levels.
■ The Camera will require 3.3V
■ The Raspberry Pi controller will require 5V
■ The Servo Motors will require 5V
■ Linear Voltage Regulators will be used to vary the voltage to the different subsystems.
■ 8V wall-outlet adapter supply will allow for stable power for each subsystem when working at maximum capacity
Requirement | Verification
Power system will supply stable voltage and accurate voltage to all the subsystems | - Voltage on both side of linear voltage regulators are accurate - Power supply is receiving power from wall outlet - Power supply is supplying power to its output
- Fold Button that will start the entire folding process. Sends a high signal to Raspberry Pi
Requirement | Verification
Folding button will start the entire folding process | - Raspberry Pi controller receives signal to start the processes - Raspberry Pi controller correctly starts once the start signal is received

- Folding Light that will inform the user when the machine is currently working and when it is ready for a new piece of clothing.
Requirement | Verification
Fold light will be active when the folding process is occuring | - Raspberry Pi controller sends power to folding light while running - Raspberry Pi controller sends no power while idling
- Physical System (Includes PCB)
- Servo Subsystem
■ The servos will be mounted using screws to a metal or wooden frame for structural support. The servos will receive power from the power supply and a SPI input from the RaspberryPi. This SPI input will tell the servos which position to rotate to, allowing the system to fold the item placed on top.
■ The servos will act in a certain order depending on the instructions that are chosen from the item on the folding table. The SPI input will be delivered when the servos need to act. This makes up our instruction order.
■ The Servos will rotate up to 120 degrees providing the necessary force and guidance duration to allow the clothes to be folded without sending them in strange directions or folding upon themselves.
■ Servos operates at 5 volts at about 20-25 mA when at rest and operates at 100mA when working.
Requirement | Verification
Servos actuate to fold the clothes | - Raspberry Pi Controller sends out signals for servo actuation - Servo’s move to correct angle at correct speed
- Camera Subsystem
■ The camera will be mounted on a rod pointing down at the mechanism. It will stream video to the RaspberryPi image recognition subsystem.
Requirement | Verification
Camera correctly captures image of the clothing item | - It is far back enough to correctly capture the folding area - Camera correctly captures and sends the image to the Raspberry Pi

- Panel Subsystem
■ Each panel will be mounted to 2 servos and will be constructed of a light-weight plastic-like material.
■ Each panel will have sections removed to allow airflow through. This prevents any major air disruptions which could cause mishaps in the folding process. This also reduces the amount of material needed to produce each panel.
Requirement | Verification
Panels can physically fold the clothes | - Clothes do not sag through panels - Panels have mounting point to connect to servos - Panels are strong enough to support clothing item
- Edge Cases
- Item not recognized
■ If an item is not recognized as one of the three in our folding categories, the folding light will turn red and blink three times.
Requirement | Verification
If an item is not recognized, folding light will turn red and blink three times | - Image identification sends out error code for unidentified object - Raspberry Pi Controller sends out error code signal - LED lights up
- No item on the folding table
■ If there is no item on the folding table, the folding light will turn red and blink once.
Requirement | Verification
If there is no item on the folding table, the folding light will turn red and blink once. | - Image identification sends out error code for empty table - Raspberry Pi Controller sends out error code signal - LED lights up

## 2.3 Supporting Material

In testing our image recognition program, we have achieved a 97.8% successful image detection rate. In a database of 70,000 clothing images, we used 60,000 to train the image recognition algorithm and tested the result on the remaining 10,000 images. This is where we achieved such a high success rate. In the future when our parts are acquired, we are going to test our image recognition program with more real-world examples.

## 2.4 Tolerance Analysis

The greatest challenge to overcome will be regulating the voltage to each sub-system as they each have a different voltage requirement. To achieve this, our design uses three different linear voltage regulators to achieve stability in the different subsystems.
The main power supply unit will be a 12V AC adaptor that will plug into a standard 120V wall outlet. The adapter provides a maximum of 3A, which provides more than our maximum draw, while having a voltage ripple of less than 200mV. Linear voltage regulators will step down the voltage to 5V for the servos and the Raspberry Pi, and 3.3V for the camera system. The use of linear voltage regulators come with two issues, heat and dropout voltage.
Dropout voltage is the minimum voltage input to get a stated voltage output and is governed by this equation:
Vin - Vout > Dropout

The maximum voltage regulator dropout voltage is 2 volts giving us the following equations:

8V - 5V > 2V
3V > 2V

To avoid thermal issues, the maximum current going out of the regulators must be below a certain number, which is governed by this equation:

Iout = (Tj - Ta)/((Vin - Vout)(Θjc + Θca))

Setting Tj = 150 , Ta = 38 , Θjc = 10, and Θca = 90, the maximum current 373mA at 5V for the servos and 238mA at 3.3V for the camera.

# 3. Cost and Schedule

## 3.1 Cost Analysis

Labor Costs
We determined hourly rates by looking at the UIUC success report from 2021-2022, as shown below.

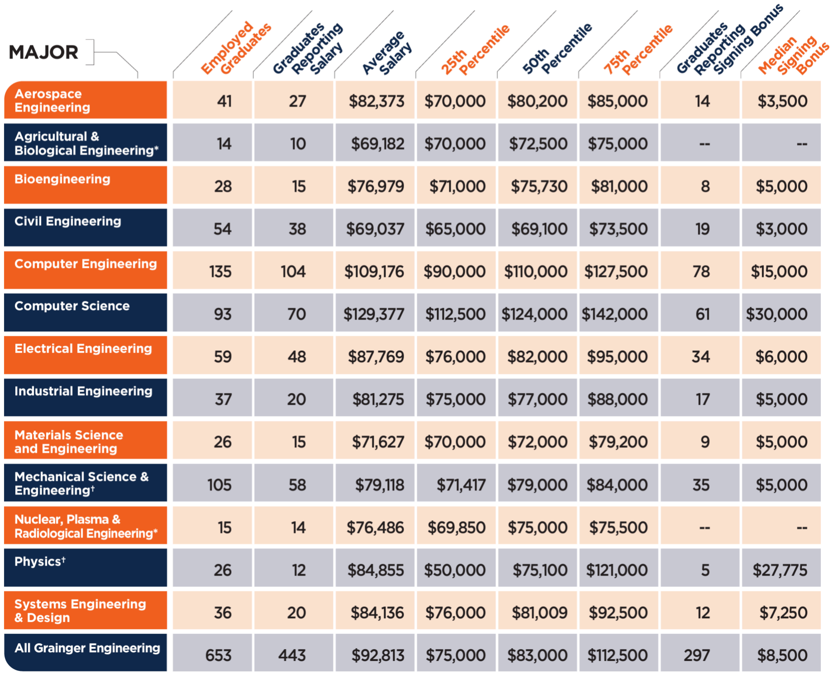
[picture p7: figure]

Figure 1. Graduate salaries of students graduating from University of Illinois

The average Computer Engineering new graduate makes $109,000 a year, divide this by (40 hrs/week * 52 weeks/year) to estimate hourly wage to be around $52. The average Electrical Engineering new graduate makes $87,000, leading to $42 per hour.
| Tyler Hirsch | Bryson Maedge | Nolan Opalski | Total
Hourly Rate ($/Hr) | 52.00 | 42.00 | 42.00 | -
Expected Labor (Hrs) | 60 | 60 | 60 | 180
Total Cost ($) | 3,120 | 2,520 | 2,520 | 8,160

Parts
Part | Part # | Specs | Quant ity | Total Cost ($)
Frame (3-D Printed) | N/A | 11 x 20 x 0.5 inches | 1 | $10.00
Panel (3-D Printed) | N/A | 10 x 10 x 0.5 inches | 6 | $30.00
Rod (3-D Printed) | N/A | 12 inches long 0.5 inches diameter | 1 | $3.00
Servo | MG996R B0BYD9M1P3 | 13.5kg/cm torque 100 mA 5 V | 12 | $51.00
RaspberryPi | Model B B07TC2BK1X | Quad Core 64-bit SoC @ 1.5 Ghz 5 V , 3A | 1 | $62.00
Camera | Arducam 5MP Camera B012V1HEP4 | 1920 x 1080 p 54 x 41 degrees of view 3.3V , 3A | 1 | $10.00
Micro SD Card | PNY 32GB Elite Class B07R8GVGN9 | 32 GB RAM 100 MB/s | 1 | $5.00
PCB | N/A | MADE TO ORDER | 1 | $5.00
Power Supply | B073WSWT34 | 12V 3A | 1 | $10.00
Voltage Regulator | B08JZ5FVLC | Input: 4.5 - 24V Output: 5V , 3A | 10 | $13.00
Total: | | | | $199.00

Part Links
Servo | https://www.amazon.com/Hosyond-MG996R-Digital-Motors-Helicopter/dp/B0BYD9M 1P3 (https://www.amazon.com/Hosyond-MG996R-Digital-Motors-Helicopter/dp/B0BYD9M1P3)
RaspberryPi | https://www.amazon.com/Raspberry-Model-2019-Quad-Bluetooth/dp/B07TC2BK1X
Camera | https://www.amazon.com/Arducam-Megapixels-Sensor-OV5647-Raspberry/dp/B012V1 HEP4 (https://www.amazon.com/Arducam-Megapixels-Sensor-OV5647-Raspberry/dp/B012V1HEP4)
Micro SD Card | https://www.amazon.com/PNY-Elite-microSDHC-Memory-P-SDU32GU185GW-GE/dp/B07R8GVGN9?th=1 (https://www.amazon.com/PNY-Elite-microSDHC-Memory-P-SDU32GU185GW-GE/dp/B07R8GVGN9?th=1)
Power Supply | https://www.amazon.com/Facmogu-Connector-5-5x2-5mm-5-5x2-1mm-Transformer/dp/B073WSWT34?th=1 (https://www.amazon.com/Facmogu-Connector-5-5x2-5mm-5-5x2-1mm-Transformer/dp/B073WSWT34?th=1)
Voltage Regulator | https://www.amazon.com/Weewooday-Regulator-Voltage-Converter-Transformer/dp/B0 8JZ5FVLC (https://www.amazon.com/Weewooday-Regulator-Voltage-Converter-Transformer/dp/B08JZ5FVLC)

Total Cost
Cost Type | Cost Value
Labor | $8,160
Parts | $199
Total | $8,359

## 3.2 Schedule

Week | Goal | Tyler | Bryson | Nolan
6 | Acquire Parts | Servo, MicroSD | Raspberry Pi, Power Supply | Camera
7 | 3D Print Materials | Design Cad | Locate Printer/Print | Locate Printer/Print
8 | Design PCB | Design the PCB | Design the PCB | Logistics/Put in order
9 Program | Raspberry Pi | Python Code | Implement | Implement
10 | Assemble | Test image recognition software | Physically put down frame/panels | Work on servos and frame
11 Assemble and | Test | Test folding sequences | Physically put down frame/panels | Work on servos and frame
12 | Practice Demo | Presentation | Presentation | Presentation
13 | Final Presentation | Succeed! | Succeed! | Succeed!

# 4. Ethics and Safety

Due to the nature of our project, many of the ethical concerns listed in the IEEE and ACM Code of Ethics are upheld naturally (for example, the codes on intelligent systems don't apply because we are not implementing that capability.) In the IEEE code of ethics, there are two codes that I find to be extremely important as we progress. These two codes are I.1 and I.5. We want to hold the safety and welfare of the general public paramount while accepting criticism and updating our machine to fulfill the initial focus of helping the user of our machine. In order to fulfill this, we initially designed our project to help people with health conditions or impairments like arthritis, cerebral palsy, and other physically limiting conditions. As we go through the designing and construction phases, we will make sure to keep that in mind and not implement anything that competes with that focus. Finally, we should thoughtfully consider improvements and feedback that are offered to us from the recipients of our project.

In the ACM Code of Ethics, the most unique and relevant ethical concerns that are not previously mentioned in the IEEE’s list are the Professional Leadership Principles. These will be paramount as a group to uphold since ultimately this is a learning opportunity. These codes of ethics pertain to allowing each member of the group to be able to contribute and best learn from this project. In order to ensure these are followed, a policy of open and considerate communication between group partners will be adopted. This will allow us to voice concerns while also considering one another’s interests and overall experience throughout the project.

For the safety concerns, our project does not fulfill any of the special concerns listed on the website. We will not be using any batteries, large voltages, and no currents will be going through human subjects. Every member of the group has completed the Lab Safety Guidelines training and will strictly adhere to the rules and overall ethos of safety first. Our system will be designed in a way that no bodily harm could result from its regular use.

# Citations and References

ACM. “”ACM Code of Ethics and Professional Conduct”.” (2018), [Online]. Available: https://www.acm.org/code-of-ethics (visited on 2/5/2024).

ADA. “”Laundromat tips for People with Disabilities”.”(2020),[Online]. Available: https://thedutchmanslaundry.com/laundromat-tips-for-people-with-disabilities/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,a%20more%20inclusive%20laundromat%20environment.

dfrobot. “”DSS-P05 Standard Servo”.” (2024), [Online]. Available: https://www.dfrobot.com/product-236.html (visited on 2/6/2024).

IEEE. “”IEEE Code of Ethics”.” (2016), [Online]. Available: https://www.ieee.org/about/corporate/governance/p7-8.html (visited on 2/5/2024).

UIUC. “”ECE 445 SAFETY GUIDELINES”.” (2024), [Online]. Available: https://courses.engr.illinois.edu/ece445/guidelines/safety.asp (visited on 2/5/2024).

UIUC “”New Graduate Average Salary””(2022), [Online]. Available: https://illinisuccess.illinois.edu/themes/custom/sasubtheme/files/2021-2022_Illini%20Success_FullReport_AllCampus%20_FINAL.pdf (visited on 2/20/2024)

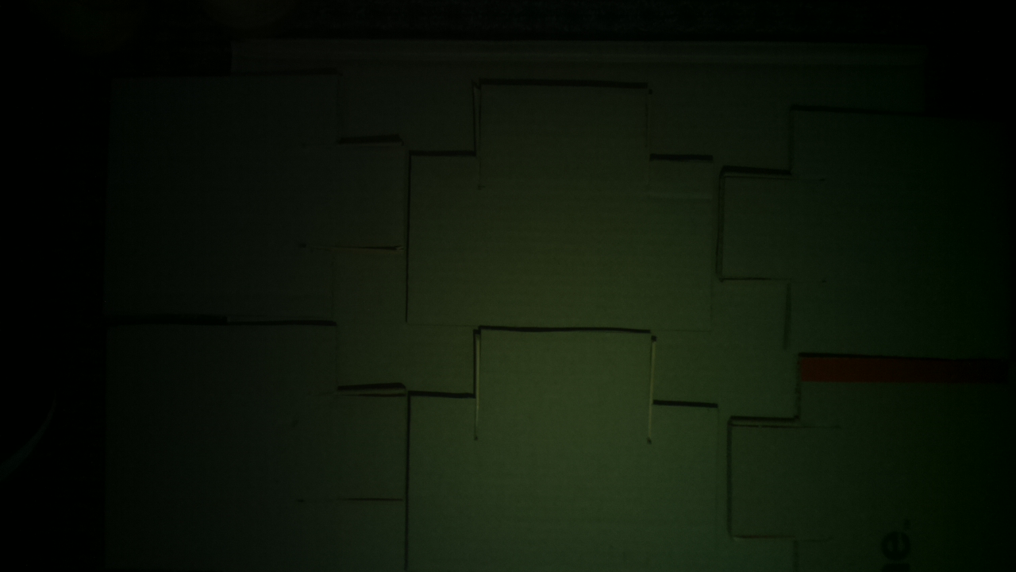
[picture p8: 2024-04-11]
python_code/rasp_pi/image.jpg

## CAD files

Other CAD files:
cad_files/Panel.ipt

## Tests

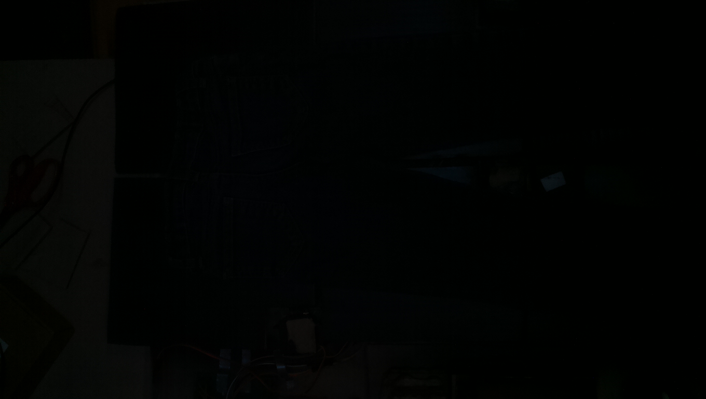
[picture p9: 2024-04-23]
python_code/experimental/pants.jpg

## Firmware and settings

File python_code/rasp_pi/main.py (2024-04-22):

from image_classification_model import *
import servo_controller_subsystem
from utils import *

model_name = "trained_model"
image_path = "image.jpg"

def main(train_model = True, evaluate_model = False):
    # Mainly used for testing and initial stages
    if train_model or evaluate_model:
        image_classification_model.load_training_data_into_memory()
        if train_model:
            model = image_classification_model.train_and_save_model(model_name)
        else:
            model = image_classification_model.load_model(model_name)
        image_classification_model.evaluate_model()

    setup_board()

    image_classification_model.load_model(model_name)
    image_classification_model.load_training_data_into_memory()
    
    # Repeat forever
    while True:
        # Wait until button is pressed
        while not button():
            pass

        # Take picture
        # take_picture(image_path)
        # Normalize picture
        image = normalize_image(image_path)
        # Pass picture into predict function
        prediction = image_classification_model.predict(image)
        print(prediction)
        # Pass output of predict function into servo-controller subsystem
        servo_controller_subsystem.main(prediction)

if __name__ == "__main__":
    main(train_model = False, evaluate_model = False)

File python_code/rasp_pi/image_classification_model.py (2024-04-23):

from keras.datasets import fashion_mnist
from keras.models import Sequential, load_model
from keras.layers import Conv2D, MaxPooling2D, Flatten, Dense
from keras.utils import to_categorical

from PIL import Image, ImageOps

import cv2
import numpy as np

'''
import picamera

def take_picture(file_path):
    with picamera.PiCamera() as camera:
        camera.capture(file_path)
'''

# TODO
def normalize_image(image_path):
    # open image
    image = Image.open(image_path)

    # rotate image to right side up
    image = image.rotate(image, 180)

    # add black space above and below
    new_image = Image.new(image.mode, size=(image.size[0], image.size[0]))
    new_image.paste(image, (0, int((new_image.size[1] - image.size[1]) / 2)))

    # resize image to proper dimensions
    image = new_image.resize((28, 28))

    image = ImageOps.grayscale(image)

    image.save('output.jpg')

    return image


class image_classification_model:
    working_set = (0, 1, 2)
        # Labels for fashion MNIST:
            # 0 T-shirt/top
            # 1 Trouser
            # 2 Pullover
            # 3 Dress
            # 4 Coat
            # 5 Sandal
            # 6 Shirt
            # 7 Sneaker
            # 8 Bag
            # 9 Ankle boot
    
    model = 0

    train_images, train_labels, test_images, test_labels = [], [], [], []

    def load_training_data_into_memory():
        # Load and preprocess the Fashion MNIST dataset
        (train_images, train_labels), (test_images, test_labels) = fashion_mnist.load_data()

        # remove uneccessary training data
        train_images = np.array(train_images)
        remove_items = []
        for ind, train_label in enumerate(train_labels):
            if train_label not in image_classification_model.working_set:
                remove_items.insert(0, ind)
            elif train_label == 1:
                image = Image.fromarray(train_images[ind])
                train_images[ind] = np.array(image.rotate(270))
        train_labels = np.delete(train_labels, remove_items, 0)
        train_images = np.delete(train_images, remove_items, 0)

        # remove unneccessary testing data
        remove_items = []
        for ind, test_label in enumerate(test_labels):
            if test_label not in image_classification_model.working_set:
                remove_items.insert(0, ind)
        test_labels = np.delete(test_labels, remove_items, 0)
        test_images = np.delete(test_images, remove_items, 0)
        
        print(set(train_labels), set(test_labels))

        # normalize data
        image_classification_model.train_images = train_images.reshape((train_images.shape[0], 28, 28, 1)).astype('float32') / 255
        image_classification_model.test_images = test_images.reshape((test_images.shape[0], 28, 28, 1)).astype('float32') / 255
        image_classification_model.train_labels = to_categorical(train_labels)
        image_classification_model.test_labels = to_categorical(test_labels)

    def train_and_save_model(model_name):
        # Define the CNN model
        model = Sequential([
            Conv2D(32, (3, 3), activation='relu', input_shape=(28, 28, 1)),
            MaxPooling2D((2, 2)),
            Conv2D(64, (3, 3), activation='relu'),
            MaxPooling2D((2, 2)),
            Conv2D(64, (3, 3), activation='relu'),
            Flatten(),
            Dense(64, activation='relu'),
            Dense(3, activation='softmax')
        ])

        # Compile the model
        model.compile(optimizer='adam',
                    loss='categorical_crossentropy',
                    metrics=['accuracy'])

        # Train the model
        model.fit(image_classification_model.train_images, image_classification_model.train_labels, epochs=5, batch_size=64, verbose=1)

        # Save the model
        model.save(model_name)
        image_classification_model.model = model
        return model

    def evaluate_model():
        # Evaluate the model
        test_loss, test_acc = image_classification_model.model.evaluate(image_classification_model.test_images, image_classification_model.test_labels, verbose=0)
        print(test_loss, test_acc)

    def load_model(model_name):
        # Load the model
        model = load_model(model_name)
        image_classification_model.model = model
        print(image_classification_model.model)
        return model
    
    def predict(image):
        convert = {
            0: "T-shirt/Top",
            1: "Trouser",
            2: "Pullover"
        }

        image = np.array(image)
        image = image.reshape(-1, 28, 28, 1)
        prediction = convert[np.argmax(image_classification_model.model.predict(image)[0])]
        return prediction

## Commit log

2024-02-10 fleshed out everything for servo control
2024-02-21 pushing start of cad files
    [Panel.ipt]
